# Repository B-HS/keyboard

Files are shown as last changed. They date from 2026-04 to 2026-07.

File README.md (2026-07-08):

# keyboard

| 브랜치 | 내용 | 뷰어 (GitHub Pages) |
| --- | --- | --- |
| [`v1`](https://github.com/B-HS/keyboard/tree/v1) | 49키 레이아웃 PCBA 뷰어 — React Three Fiber 기반 1세대 설계 | [b-hs.github.io/keyboard/v1](https://b-hs.github.io/keyboard/v1/) |
| [`v2`](https://github.com/B-HS/keyboard/tree/v2) | 49키 핸드와이어드 무선(BLE) + USB-C 키보드 빌드 — 2세대 | [b-hs.github.io/keyboard/v2](https://b-hs.github.io/keyboard/v2/) |
| [`split`](https://github.com/B-HS/keyboard/tree/split) | **현행** — split-65(65키 분리형) + split-keypad 모노레포. JSCAD 파라메트릭 케이스(FDM 7.5° 틸트, ESP32-C3 크래들), React 19 + three.js 뷰어, KiCad PCB(핫스왑·DO-35 손납땜·JLCPCB 발주본) | [b-hs.github.io/keyboard/split](https://b-hs.github.io/keyboard/split/) |

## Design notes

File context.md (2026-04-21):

# 49 Keyboard 프로젝트 Context

대화 재개용 요약. 이 파일 읽으면 전체 맥락 파악 가능.

**상태: JLC3DP 주문 완료 (SLA Resin + Threaded Insert)**

---

## 🎯 프로젝트 개요

**목표**: 49키 커스텀 키보드 자체 제작 (핸드와이어드, USB-C 유선, 3D 프린팅 케이스)

**핵심 스펙**:
- 레이아웃: 49키 (Row 0: 14×1u / Row 1: 1.5+11×1u+1.5u / Row 2: 2+10×1u+2u / Row 3: 1u+2×1.25u+2×2.75u(split spacebar)+5×1u)
- 컨트롤러: **LOLIN S3 Mini** (ESP32-S3FH4R2)
- 펌웨어: **RMK (Rust)** — Vial 네이티브
- 연결: **USB-C 유선 전용** (무선·배터리 완전 제거)
- 플레이트: **사용자 제공 STL** (`docs/models/plate/keyboard-plate.stl`)
- 케이스: **3D 프린팅 상/하 분할 + 샌드위치 구조**
- 타이핑 각도: **8° 틸트**
- 체결: **M3×6 button head × 8개** (모두 통일)

---

## 📂 프로젝트 구조

`/Users/gkn/keyboard/` (Git: github.com/B-HS/keyboard)

```
keyboard/
├── src/
│   ├── app.tsx                  # HMR accept + model re-build 트리거
│   ├── vite-env.d.ts
│   ├── components/
│   │   ├── viewer.tsx           # Blender/KiCad 스타일 카메라
│   │   └── controls.tsx         # 사이드바 + SLA toggle
│   └── models/
│       ├── layout.ts            # 49.json 파싱
│       ├── plate.ts             # buildPlate + loadPlateGeom (STL)
│       ├── case.ts              # 메인 케이스 빌더 (DEFAULT/SLA params)
│       ├── lolin.ts             # LOLIN S3 Mini 시각화
│       ├── switch.ts            # Cherry MX STL 로드
│       ├── keycap.ts            # Cherry MX 키캡 STL 로드
│       ├── stabilizer.ts        # 스태빌 STL 로드
│       ├── accessories.ts       # 고무발 / 스태빌 geometry
│       ├── reference.ts         # 49-final.jscad 파서
│       ├── defaults.ts          # 플레이트 파라미터 override
│       ├── build-params.ts
│       ├── build-solids.ts      # 조립 + SLA/default 선택
│       └── index.ts             # public API (loadPlateGeom 포함)
├── scripts/
│   ├── export.ts                # STL export + insert-spec 생성
│   ├── generate-spec.ts         # SVG/PNG spec 생성 (resvg-js)
│   ├── load-defaults.ts
│   └── verify.ts                # 치수 검증
├── docs/
│   ├── models/
│   │   ├── 49-final.jscad       # 레퍼런스 (fallback용)
│   │   ├── 49.json              # KLE 레이아웃 (truth source)
│   │   ├── plate/
│   │   │   ├── keyboard-plate.stl   # ⭐ 사용자 제공 plate (source of truth)
│   │   │   └── plate.jscad          # KLE-NG 출처
│   │   ├── switch/cherry mx.*
│   │   ├── keycap/STL/*.stl
│   │   └── stabilizer/*.stl
│   └── export/                  # JLC 주문용 산출물
│       ├── 1_case-top.stl               # PA12 self-tap
│       ├── 2_case-bottom.stl            # PA12 self-tap
│       ├── 1_case-top_SLA.stl           # SLA insert ⭐
│       ├── 2_case-bottom_SLA.stl        # SLA insert ⭐
│       ├── insert-spec-case-top.svg/png
│       └── insert-spec-case-bottom.svg/png
├── .github/workflows/deploy.yml
├── vite.config.ts               # base: '/keyboard/'
├── tsconfig.json                # noEmit: true
└── context.md
```

---

## 🏗 샌드위치 구조 (현재 설계)

```
위
│   [Keycaps]           ← 키캡 (외부)
│┌─────────────────────┐
││  Top Case           │ ← 상판 (뚜껑 역할, 옆벽 체결 4 insert)
││  ┌───────────────┐  │
││  │    Switches   │  │
││  ├───────────────┤  │
││  │     Plate     │  │ ← plate (사용자 STL, 기둥 위에 얹힘)
││  ┌─┴────────┐┌──┴┐  │
││  │          ││   │  │ ← 4 기둥 (하판에서 솟음, 상단 tilted)
││  │  LOLIN   ││   │  │
││  └──────────┘└───┘  │
│└──╧═══════════════╧──┘ ← 하판 (floor + pillars + 옆벽 체결 관통)
아래
```

**핵심 특징**:
- Plate은 하판의 4개 수직 기둥 위에 얹힘 (tilted pocket으로 8° 정렬)
- Top case는 뚜껑처럼 씌워져 옆벽 2/4·3/4 Y 위치에서 하판과 체결
- 조립 순서: 하판 → plate 장착 → 스위치/핸드와이어 → 상판 씌움

---

## 🔧 확정된 설계 결정 (최종)

1. **무선·배터리 완전 제거** → USB-C 유선 전용
2. **펌웨어 RMK** (Rust): Vial 네이티브, USB-C only
3. **MCU ESP32-S3** (LOLIN S3 Mini, 양면폼으로 하판 고정)
4. **케이스 샌드위치**: 하판(floor+기둥) + plate + 상판(뚜껑)
5. **Plate은 사용자 STL**: `keyboard-plate.stl`, 케이스가 자동으로 bounds에 맞춰 스케일
6. **8° 틸트**, pivot Y=plateBounds.minY, plateFrontBottomZ=10
7. **벽 두께 2mm**, case margin 2mm 사방
8. **Upper wall inset**: X=2, Y=2 (키캡-벽 gap: 좌우 1mm, 앞 2.48mm, 뒤 0.48mm)
9. **옆벽 체결**: Y=2/4, 3/4 위치, 좌우 총 4개 (6×6×6mm 보스)
10. **기둥**: 4개, plate 나사홀 위치, 수직 원기둥 (top만 tilted)
11. **Plate mount head clearance hole**: 상판 upper wall에 Ø5.2×3mm, tilted 정렬
12. **USB-C cutout 단순화**: 단일 관통홀 (Ø12.2×5.5 × depth 4mm, no taper)
13. **나사 통일**: M3×6 button head (head Ø5×H2, thread Ø3×L6) × 8개

---

## 📐 현재 케이스 파라미터 (case.ts)

### DEFAULT_CASE_PARAMS (PA12 SLS self-tap)

```ts
caseMarginFront/Back/Left/Right: 2
plateTiltDeg: 8
plateFrontBottomZ: 10

plateRecessWall: 7.5
wallThickness: 2
upperWallInsetX: 2
upperWallInsetY: 2
bottomThickness: 2.4

// Side fastener (옆벽 체결, 4개)
sideFastenerSize: 6          // 6×6mm 보스
sideFastenerHeight: 6.0      // 보스 높이
sideFastenerInsertRadius: 1.25   // Ø2.5 self-tap pilot
sideFastenerInsertDepth: 4.0
sideFastenerThroughRadius: 1.7   // Ø3.4 하판 관통
sideFastenerHeadRadius: 2.6      // Ø5.2 counterbore
sideFastenerHeadDepth: 2.0       // M3 button head 높이
sideFastenerYRatios: [0.5, 0.75]

// Plate mount pillar (하판 기둥, 4개)
plateMountPostRadius: 2.5        // Ø5 기둥
plateMountInsertRadius: 1.25     // Ø2.5 self-tap
plateMountInsertDepth: 4.0
plateMountHeadRadius: 2.6        // 상판 head clearance
plateMountHeadHeight: 2.5

// USB-C
usbCutoutWidth: 12.2, usbCutoutHeight: 5.5
usbCutoutCenterX: 9.7, usbCutoutCenterZ: 7.0
usbCutoutCornerRadius: 1.5

caseCornerRadius: 2
```

### SLA_CASE_PARAMS (SLA Resin + brass insert) — **주문한 버전**

```ts
...DEFAULT_CASE_PARAMS,
plateMountPostRadius: 3.0        // Ø6 (insert 주변 1.2mm wall)
plateMountInsertRadius: 1.8      // Ø3.6 (M3*4*5 insert용)
plateMountInsertDepth: 7.0       // 5mm insert + 2mm 여유
sideFastenerInsertRadius: 1.8    // Ø3.6
sideFastenerInsertDepth: 7.0
sideFastenerHeight: 8.0          // 7mm pocket + 1mm cap
```

### 최종 외곽 치수 (사용자 plate STL 기준)

- **Plate**: 271.65 × 82.10 × 1.5mm (사용자 STL)
- **Case outer**: 275.65 × 86.10mm
- **앞 높이**: ~18.5mm / **뒤 높이**: ~30.6mm

### 주요 위치 (case 좌표)

- **Plate 나사홀 (= 기둥 XY)**: (−8.999, 8.476), (256.649, 8.476), (−8.999, −67.625), (256.649, −67.625)
- **옆벽 체결**: X=−9/256.65, Y=−29.575 (2/4) / Y=−7.05 (3/4)
- **USB-C**: X=9.7, Z=7 (뒷벽)

---

## 🔨 케이스 빌드 순서 (case.ts)

### buildCaseTop (상판)
1. `outerShell` (사다리꼴 polygon extrude + R2 라운딩)
2. Z slicer로 Z ≥ bottomThickness 부분만
3. `steppedInnerCavity` subtract (plate top plane 기준 stepped)
4. `sideFastenerBosses` union (4개 옆벽 보스)
5. Subtract: `usbCutout`, `sideFastenerInsertHoles`, `plateMountHeadClearance`
6. `retessellate`

### buildCaseBottom (하판)
1. `floorSlab` (단순 roundedRectangle extrude, Z=0~2.4) — mesh 깔끔
2. `plateMountPillars` union (4개 수직 원기둥, 상단은 tilted plane으로 clip)
3. Subtract: `plateMountInsertPockets` (tilted), `sideFastenerThroughs` (counterbore + through hole)
4. `retessellate`

### Plate 렌더링
- `loadPlateGeom()` (src/models/plate.ts) — STL deserialize
- `plateBoundsFromGeom()` — bounds 자동 추출
- `applyPlateTransform()` — 8° tilt 적용

**상/하 분리**: 별도 함수 (slice 방식 버림). 완전히 독립된 빌드.

---

## 🧩 부품 (뷰어 토글)

| 부품 | 기본 | 비고 |
|---|---|---|
| Case Top | ON | |
| Case Bottom | ON | |
| Plate | ON | STL 로드 |
| Switches | ON | Cherry MX STL |
| LOLIN S3 Mini | ON | 양면폼 고정 가정 |
| Stabilizers | ON | STL |
| Keycaps | ON | 폭×R 매핑 |
| Foot Pads | ON | Ø6×2 × 4개, 코너 inset 5 |
| Phone | OFF | 크기 비교용 |
| WOBKEY Zen 65 | OFF | 크기 비교용 |
| **SLA Variant** | **OFF** | 체크하면 SLA_CASE_PARAMS 사용 |

**제거된 부품** (무선 관련): Battery Cover, Magnets, Batteries, Battery Contacts, Perf Board, Slide Switch

---

## 📦 Export (docs/export/)

```bash
bun run export
```

생성 파일:

| 파일 | 용도 |
|---|---|
| `1_case-top.stl` | PA12 SLS self-tap (대안) |
| `2_case-bottom.stl` | PA12 SLS self-tap (대안) |
| **`1_case-top_SLA.stl`** | **SLA Resin + M3*4*5 insert ⭐** |
| **`2_case-bottom_SLA.stl`** | **SLA Resin + M3*4*5 insert ⭐** |
| `insert-spec-case-top.svg/png` | JLC 참조 도면 (부품별) |
| `insert-spec-case-bottom.svg/png` | JLC 참조 도면 (부품별) |

Insert spec 자동 생성: `scripts/generate-spec.ts` + `@resvg/resvg-js`.

---

## 🛒 부품 / 주문 상태

### ✅ JLC3DP 주문 완료
- **1_case-top_SLA.stl** (SLA Resin + Threaded Insert M3*4*5 × 4)
- **2_case-bottom_SLA.stl** (SLA Resin + Threaded Insert M3*4*5 × 4)
- **Insert 총 8개** 자동 설치되어 배송
- JLC preview 노란 경고는 있지만 붉은 오류(unprintable) 없음

### ✅ 보유 부품
- LOLIN S3 Mini
- Cherry MX × 49, 키캡 STL
- MX Plate-mount 스태빌 (2u × 2 + 2.75u × 2)
- 1N4148 × 300, UEW 0.6mm × 10m, 만능보드 70×90
- M3×6 button head × 44 pack
- 고무발 Ø6×2
- HAKKO FX-600 + RS63 + 플럭스펜 + 캡톤 + 폼테이프
- 양면폼 테이프 (LOLIN 고정용)

### ❌ 추가로 필요할 수 있음
- **Plate 별도 주문** (keyboard-plate.stl — 사용자 파일 그대로)
- **Krytox 205g0** (스태빌 튜닝, 선택)

---

## 🔩 조립 순서

1. SLA 케이스 수령 (insert 8개 기 설치됨)
2. Insert에 M3 나사 시험 삽입 → 헛돌거나 안 박히면 JLC에 컴플레인
3. 하판 기둥 4개 위에 plate 얹기
4. **M3×6 × 4개** 위에서 plate 나사홀 → pillar insert 체결 (tilted 축)
5. Plate에 Cherry MX 스위치 clip 장착
6. 스위치에 다이오드 + UEW 에나멜선 핸드와이어
7. LOLIN S3 Mini에 와이어 납땜, 하판에 양면폼으로 고정
8. USB-C 연결 테스트
9. 상판을 위에서 씌움 (기둥 피하면서)
10. **M3×6 × 4개** 하판 아래에서 → 옆벽 insert 체결
11. 키캡 장착

---

## 🎨 개발 / 뷰어

```bash
bun run dev        # http://localhost:5173
bun run export     # STL + insert-spec 자동 생성
bun scripts/verify.ts   # 치수 검증 + plate STL alignment 확인
bun run build      # 프로덕션
```

**카메라 조작 (Blender/KiCad 스타일)**:
- LMB/MMB 드래그: 회전 (orbit)
- RMB or Shift+드래그: 이동 (pan)
- 휠: 커서 위치 기준 줌
- F 키: 모든 솔리드에 맞춰 프레이밍

**HMR**: `import.meta.hot.accept('./models/...')` — 모델 파일 변경시 자동 재렌더

---

## 🌐 GitHub Pages 배포

- `vite.config.ts`: `base: '/keyboard/'` (build 시만)
- `.github/workflows/deploy.yml`: main push → 자동 배포
- URL: **https://b-hs.github.io/keyboard/**

---

## 🔧 툴체인 버전

- **Vite 8.0.9**
- **React 19.2.5**
- **TypeScript 6.0.3**
- **Bun 1.3.0**
- `@resvg/resvg-js 2.6.2` (SVG→PNG 렌더링)

---

## ⏳ 남은 작업

- [ ] JLC3DP 배송 대기
- [ ] Plate 별도 주문 (`keyboard-plate.stl`)
- [ ] 배송 후 insert 품질 체크
- [ ] RMK `keyboard.toml` 작성 (Row/Col 핀 매핑, Vial 키맵)
- [ ] 핸드와이어 조립 + 테스트
- [ ] GitHub Pages 배포 확인

---

## 🐛 주요 수정 이력 (최신 순)

### 주문 직전 최종 수정
- **floorSlab** 단순화: `outerShell` slice → `roundedRectangle` extrude (JLC zigzag unprintable 에러 해결)
- **Pillar 수직화**: tilted cylinder → vertical cylinder + tilted top clip (mesh 깔끔)
- **SLA pocket**: Ø4×5 → **Ø3.6×7mm** (JLC 실제 hole 요구사항 반영)
- **SLA pillar** Ø5→Ø6 (Ø3.6 insert 주변 wall 1.2mm 확보)
- **플레이트 나사머리 clearance** 상판에 추가 (Ø5.2×3mm, tilt 정렬)
- **upperWallInsetY** 3 → 2 (back 음수 gap → 양수로)
- **plateFrontBottomZ** 9.75 → 10 (stab clip 여유)

### 구조 재설계
- **무선 관련 전면 제거**: 배터리 케이스·커버·자석·슬라이드 스위치·배터리·만능보드
- **샌드위치 구조 재설계**: plate를 하판 기둥에 직결, 상판은 뚜껑, 옆벽 2/4·3/4 체결 4개
- **플레이트 → STL 로드 방식**: 코드 generate 대신 사용자 파일 사용, 자동 bounds 추출
- **Case auto-scale to plate**: plate STL만 바꾸면 케이스 자동 맞춤

### 뷰어/카메라
- **Blender/KiCad 스타일 카메라**: LMB/MMB orbit, RMB pan, cursor zoom, F key framing
- **SLA toggle**: 뷰어에서 PA12 / SLA 전환

### 체결 규격 통일
- **M3×6 button head × 8개**로 완전 통일 (plate 4 + side 4)
- PA12 self-tap: Ø2.5 pilot × 4mm
- SLA insert: Ø3.6 × 7mm depth, M3*4*5 황동 insert

### Export 파이프라인
- **insert-spec SVG/PNG 자동 생성**: `scripts/generate-spec.ts` + resvg-js
- 부품별 2개 spec 파일 분리 (case-top / case-bottom)

### 초기 무선 제거 세션
- `case.ts`에서 battery tray, slide switch cutout, magnet boss/pocket, battery cover opening 코드 제거
- `accessories.ts`에서 `buildPerfBoard`, `buildSlideSwitch`, `buildBatteries`, `buildBatteryContacts`, `buildCaseMagnets`, `buildCoverMagnets`, `buildBatteryCover` 제거
- `build-solids.ts` · `controls.tsx` · `app.tsx`에서 관련 PartVisibility 전부 제거

---

## 🔗 외부 참조

- LOLIN S3 Mini: https://www.wemos.cc/en/latest/s3/s3_mini.html
- RMK: https://rmk.rs/ / https://github.com/HaoboGu/rmk
- Vial: https://vial.rocks/
- JLC3DP Threaded Insert: https://jlc3dp.com (SLA + Surface finish: Threaded Insert, type M3*4*5)

---

## 🎬 새 대화에서 시작

1. 이 파일 읽어 맥락 파악
2. `src/models/case.ts` 현재 상태 확인 (`DEFAULT_CASE_PARAMS` / `SLA_CASE_PARAMS`)
3. `bun run dev` (사용자 실행)
4. `bun run export` — STL + insert-spec 재생성
5. `bun scripts/verify.ts` — plate STL alignment 확인
6. JLC3DP 배송 완료시 insert 삽입 상태 검수

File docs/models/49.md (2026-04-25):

- 40% splite with `[`, `]`, `;`, `'`, `,`, `<`, `>`, `/` keys

```json
[["Esc","Q","W","E","R","T","Y","U","I","O","P","{\n[","}\n]","Back\nSpace"],
[{"w":1.5},"Tab","A","S","D","F","G","H","J","K","L",":\n;","\"\n'",{"w":1.5},"Enter"],
[{"w":2},"Shift","Z","X","C","V","B","N","M","<\n,",">\n.","?\n/\nUp",{"w":2},"Shift"],
["Control",{"w":1.25},"Option",{"w":1.25},"Command",{"w":2.75},"Space","Fn",{"w":2.75},"Space","Left","Down","Right\nDown","Fn\nRight"]]
```

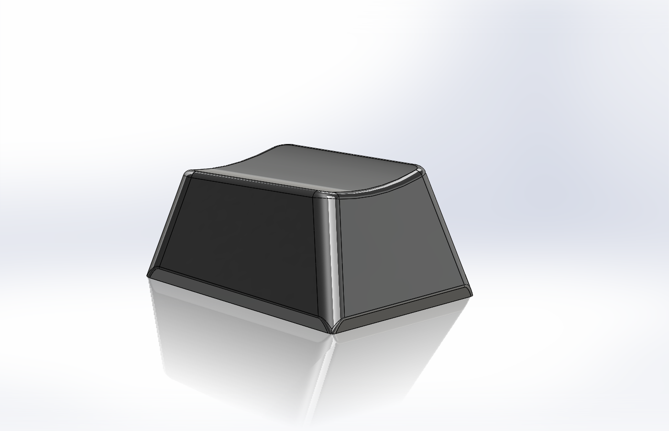
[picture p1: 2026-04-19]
docs/models/keycap/Cherry MX Keycap.PNG

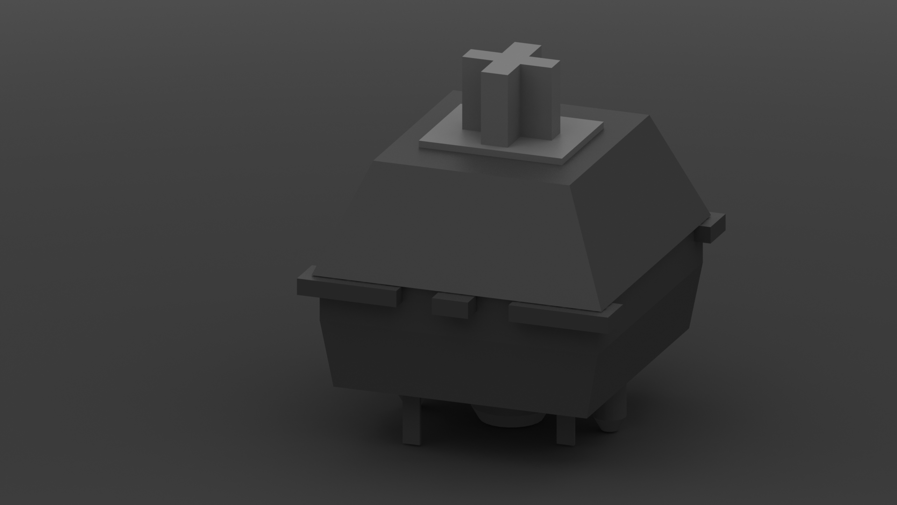
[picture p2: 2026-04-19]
docs/models/switch/cherry.JPG

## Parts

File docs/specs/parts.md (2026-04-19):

# 49 Keyboard 부품 리스트

49키 핸드와이어드 + 무선(BLE) + USB-C 키보드 빌드.

## 확정 사양

| 항목 | 값 |
|---|---|
| 레이아웃 | 49키 (`docs/keyboard-plate.jscad` 기반) |
| 컨트롤러 | LOLIN S3 Mini (ESP32-S3FH4R2) |
| 펌웨어 | RMK (Rust, Vial 네이티브) |
| 키맵 편집기 | Vial (vial.rocks) |
| 연결 | USB-C 유선 + BLE 5.0 무선 자동 전환 |
| 전원 | 3×AA 알카라인 교체형 |
| 배터리 구획 | 케이스 일체형 슬롯 + 스프링 접점 |
| 커버 | 슬라이드 + 스냅핏 |
| 매트릭스 | 7×7 + diode per key |
| 플레이트 | 파라메트릭 (STL 출력 예정) |
| 케이스 | JSCAD 커스텀 3D 프린팅 |

---

## 부품 마스터 테이블

| 상태 | 카테고리 | 부품 | 수량 | 비고 |
|:----:|---|---|:----:|---|
| `[x]` | 컨트롤러 | LOLIN S3 Mini (ESP32-S3FH4R2) | 1 | Xtensa LX7, 27 GPIO, USB-C, BLE 5.0 |
| `[x]` | 전원 | AA 스프링 접점 세트 10개 | 1 | 콤비×2 + 플레이트×1 + 스프링×1 필요 |
| `[x]` | 전원 | TPS63020 Buck-Boost 3.3V 모듈 | 1 | 3.3V 출력 버전. PS→GND 필수 |
| `[x]` | 전원 | GVMRZ 슬라이드 스위치 (SMD) | 1 | 케이스 내부 배치, 1.5mm 핀 간격 |
| `[x]` | 전원 | AA 알카라인 배터리 | 3+예비 | 장기 미사용 시 분리 |
| `[x]` | 매트릭스 | 1N4148 다이오드 (DO-35) | 300 | 극성: 검은 띠=Cathode(−) |
| `[x]` | 매트릭스 | 에나멜선 0.6mm 10m (UEW) | 1 | 22 AWG 상당, 인두 330~350°C |
| `[x]` | 매트릭스 | 만능보드 7×9cm (70×90mm) 양면 FR4 | 1 | LOLIN + TPS63020 + 슬라이드 스위치 마운트용 |
| `[x]` | 스위치 | Cherry MX 호환 스위치 | 49 | 보유 |
| `[x]` | 스위치 | 키캡 세트 | 49 | 보유 |
| `[x]` | 스위치 | MX Plate-mount 스태빌라이저 2u | 2세트 | 보유 (좌/우 Shift) |
| `[x]` | 스위치 | MX Plate-mount 스태빌라이저 6.25u | 1세트 | 보유 (Space) |
| `[x]` | 연결 | USB-C 데이터 케이블 | 1 | 데이터 지원 확인 |
| `[x]` | 조립 | M3 하드웨어 키트 (나사+너트+스페이서 176pcs) | 1 | M3×6mm 44개 + 너트 44개 + F-F/F-M 스페이서 다양 |
| `[x]` | 조립 | M3 열 인서트 키트 (M2~M6, 220pcs) | 1 | M3×4×4 25개 + M3×5×4 25개 + 기타 다양 |
| `[x]` | 조립 | 고무발 실리콘 6×2mm 자가접착 | 100 | 케이스 바닥 (필요 시 겹쳐 사용) |
| `[x]` | 소모품 | 희성 일반 유연납 0.6mm 500g | 1 | Sn63/Pb37 |
| `[x]` | 소모품 | 엑소 QSP-57 솔더링 페이스트 | 1 | 친환경 페이스트 |
| `[x]` | 소모품 | 켐트로닉스 CW-8200 플럭스펜 | 1 | No-clean 플럭스 펜 |
| `[x]` | 소모품 | 3M 8997 캡톤 PI테이프 15mm × 33m | 1 | 절연·교차점·열 보호 (열수축튜브 대체) |
| `[x]` | 소모품 | 3M 4421 양면 폼테이프 10mm × 10m | 1 | 모듈·스위치·배터리 고정 |
| `[x]` | 도구 | 글루건 + 글루 스틱 | 1 | 보유. AA 스프링 접점 고정용 |
| `[x]` | 도구 | HAKKO FX-600 인두기 | 1 | T18 팁 시리즈, 200~500°C |
| `[x]` | 도구 | HAKKO FH300 스탠드 | 1 | FX-600 전용 |
| `[x]` | 도구 | HAKKO T18-D24 팁 (치즐 2.4mm) | 1 | 일반 작업용 |
| `[x]` | 도구 | HAKKO T18-D08 팁 (치즐 0.8mm) | 1 | SMD 세밀 작업용 |
| `[x]` | 도구 | HAKKO WICK FR551-3015 (솔더윅) | 1 | 납 제거 |
| `[x]` | 도구 | HAKKO 599-029 클리닝 와이어 | 1 | 팁 청소 |
| `[x]` | 도구 | PLATO 170S 정밀 니퍼 (플러시 컷) | 1 | 구리 0.8mm 까지 절단 |
| `[x]` | 도구 | 새한 ST-850A 디지털 멀티미터 | 1 | 매트릭스 QA |
| `[ ]` | 출력 | 스위치 플레이트 3D 프린팅 | 1 | `docs/keyboard-plate.jscad` |
| `[ ]` | 출력 | 케이스 상부 3D 프린팅 | 1 | JSCAD 설계 후 |
| `[ ]` | 출력 | 케이스 하부 3D 프린팅 | 1 | JSCAD 설계 후 |

---

## 기타 (49키 빌드와 무관)

| 상태 | 부품 | 용도 |
|:----:|---|---|
| `[x]` | ESP32 2.8" 스마트 디스플레이 (CYD, LVGL) | 별도 실험용 |

---

## 빌드 단계 체크리스트

### Phase 1. CAD 설계
- [x] 49.json 레이아웃 확정
- [x] 플레이트 파라메트릭 모델 (`docs/keyboard-plate.jscad`)
- [x] JSCAD 뷰어 셋업 (`viewer/`)
- [ ] 케이스 상부 프레임 설계
- [ ] 케이스 하부 설계 (배터리 슬롯 + 컨트롤러 마운트 + 슬라이드 커버)
- [ ] 최종 STL 내보내기

### Phase 2. 부품 주문
- [x] 전원 부품 (접점, TPS63020, 스위치)
- [x] 매트릭스 부품 (다이오드, 선, 만능보드)
- [x] 조립 하드웨어 (나사, 너트, 스페이서, 고무발, 열 인서트)
- [x] 소모품 (납, 플럭스, 테이프)
- [x] 도구 (인두기 + 팁 + 니퍼 + 멀티미터)
- [ ] 3D 프린팅 의뢰

### Phase 3. 하드웨어 조립
- [ ] 스위치를 플레이트에 장착
- [ ] 스태빌라이저 설치 (2u×2, 6.25u×1)
- [ ] 만능보드에 부품 고정 (LOLIN, TPS63020, 슬라이드 스위치)
- [ ] 다이오드 납땜 (49개)
- [ ] Row 배선 (UEW, 7줄)
- [ ] Col 배선 (UEW, 7줄)
- [ ] 배터리 접점 설치
- [ ] 전원 회로 (접점 → 스위치 → TPS63020 → LOLIN 3.3V)
- [ ] LOLIN GPIO ↔ 매트릭스 14줄 배선
- [ ] 멀티미터 QA
- [ ] 케이스 조립

### Phase 4. 펌웨어
- [ ] Rust + ESP-IDF toolchain 설치
- [ ] RMK 리포지토리 클론
- [ ] `keyboard.toml` 작성 (49키 매트릭스 + GPIO 매핑)
- [ ] 첫 빌드 + USB-C 플래싱
- [ ] vial.rocks 키맵 편집 테스트
- [ ] BLE 페어링 테스트 (Mac/Win/iOS)
- [ ] 슬립/절전 튜닝

### Phase 5. 마감
- [ ] 고무발 부착
- [ ] 배터리 삽입 + 무선 동작 확인
- [ ] 장기 사용 테스트

---

## 의사결정 로그

| 결정 | 사유 |
|---|---|
| 펌웨어 RMK | QMK+BT+VIA 조합 불가. RMK = Vial(VIA 호환) 네이티브 + BLE/USB 듀얼 |
| MCU ESP32-S3 | nRF52840 대비 국내 구매 용이, USB-C 네이티브, RMK 공식 지원 |
| LOLIN S3 Mini | 27 GPIO, 공식 제품, USB-C |
| 3×AA 알카라인 교체형 | 리튬 수명(~2년) 대비 반영구. 장기 미사용 시 분리 가능 |
| 통합 슬롯 + 스프링 접점 | 완제품 홀더 대비 슬림. AA 표준 치수로 사전 설계 가능 |
| 슬라이드 + 스냅핏 커버 | 공구 없이 교체, 외부 돌출 없음 |
| UEW 0.6mm 단일 | 국내 구매 가능한 굵기. Row/Col 통일 단순화 |
| TPS63020 Buck-Boost | AA 전압 변동(4.5→2.7V) 전체에서 3.3V 유지 |
| 슬라이드 스위치 내부 배치 | 외부 돌출 없음. 배터리 커버 열어 조작 |
| 유연납 0.6mm | 작업성 우위. 환기 + 손 세정으로 안전 관리 |
| 캡톤 + 폼테이프 | 열수축튜브·순간접착제 대체. 가열 도구 불필요 |
| 만능보드 7×9cm | 부품 마운트 전용 (매트릭스는 직접 배선) |

---

## 참조

- **LOLIN S3 Mini 공식**: https://www.wemos.cc/en/latest/s3/s3_mini.html
- **RMK 문서**: https://rmk.rs/
- **RMK GitHub**: https://github.com/HaoboGu/rmk
- **Vial**: https://get.vial.today/ · 웹: https://vial.rocks/
- **ESP32-S3 Datasheet**: https://www.espressif.com/sites/default/files/documentation/esp32-s3_datasheet_en.pdf
- **자세한 부품 치수**: `parts_specification.md`

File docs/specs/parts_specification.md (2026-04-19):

# 부품 치수·사양 명세

케이스·플레이트 JSCAD 설계에 사용되는 각 부품의 실제 치수.

구분:
- **✅ 확정**: 공식 데이터시트/사용자 제공/표준치 기반
- **⏳ 실측 필요**: 실물 도착 후 사용자가 재봐야 함
- **❓ TBD**: 아직 결정/확인 안 됨

---

## 1. 플레이트 / 레이아웃

### 1.1 플레이트 아웃라인 ✅
소스: `docs/keyboard-plate.jscad` (KLE-NG 생성, `viewer/src/models/reference.ts` 파서로 자동 반영)

| 항목 | 값 |
|---|---|
| 크기 | 271.65 × 83.15 mm |
| 두께 | 1.5 mm |
| 코너 R | 1.0 mm |
| 중심 좌표 | (123.825, -29.575) |

### 1.2 키 배치 ✅
소스: `49/49.json` KLE 레이아웃

| 항목 | 값 |
|---|---|
| 총 키 수 | 49 |
| 키 피치 | 19.05 mm (1u) |
| 행 수 | 4 |
| 키 bounding box | X [-9.525, 257.175], Y [-66.675, 9.525] |

### 1.3 스위치 컷아웃 ✅

| 항목 | 값 |
|---|---|
| 크기 | 14 × 14 mm |
| 코너 R | 0.5 mm |

### 1.4 스태빌라이저 컷아웃 ✅
대상: `2,0` (2u), `2,12` (2u), `3,6` (6.25u)

| 항목 | 값 |
|---|---|
| 패드 크기 | 7 × 15 mm |
| 패드 코너 R | 0.5 mm |
| Y 오프셋 (키 중심 기준) | -1.5 mm |
| 2u 스페이싱 | ±11.938 mm |
| 6.25u 스페이싱 | ±50 mm |

### 1.5 나사홀 ✅

| 항목 | 값 |
|---|---|
| 개수 | 4 (코너) |
| 반경 | 1.5 mm (M3 통과) |
| 아웃라인 엣지로부터 마진 | 3.0 mm |
| 위치 | (-9, -68.15), (256.65, -68.15), (-9, 9), (256.65, 9) |

---

## 2. 컨트롤러

### 2.1 LOLIN S3 Mini (ESP32-S3FH4R2)
소스: `dim_s3_mini_v1.0.0.pdf` 공식 치수

| 항목 | 값 |
|---|---|
| 바운딩 박스 | **25.4 × 34.3 mm** |
| PCB 두께 | 1.6 mm |
| 전체 두께 (부품 포함) | ~4~5 mm |
| USB-C 위치 | 짧은 변 (25.4 mm) 상단 끝 (34.3mm 중 한쪽 끝) |
| USB-C 엣지 범위 | 엣지 좌측 2.5 mm ~ 우측 2.5 mm (폭 20.4 mm) |
| USB-C 엣지 돌출량 | ~1 mm (추정, 실측 권장) |
| ANT (BLE 안테나) | 우측 상단 코너, Ø2 mm, 상단에서 7.7 mm |
| 핀헤더 | 2×16 (양측) 2.54 mm 피치 |
| 좌측 핀헤더 | 좌측 엣지에서 1.27 mm 안쪽 |
| 우측 핀헤더 | 우측 엣지에서 1.27 mm 안쪽 |
| 최하단 핀 위치 | 상단에서 8.2 mm 이후부터 시작 (8.8 mm down) |
| 마운트 홀 | **없음** |
| 동작 전압 | 3.3V |

**핀 사용 제약**:
- 스트랩 핀 (부팅 영향): IO0, IO3, IO45, IO46 — 가급적 회피
- USB: IO19 (D−), IO20 (D+) — USB 쓸 땐 건드리지 말 것
- RGB LED (WS2812): IO47 — 안 쓰면 GPIO 로 자유
- EN 버튼, BOOT (IO0) 버튼 — 온보드 존재

**JSCAD 케이스 설계 반영**:
- LOLIN 마운트 영역: **25.4 × 34.3 mm + 2~3mm 여유**
- 마운트 홀 없으므로 **만능보드에 핀헤더로 고정** (만능보드가 고정 역할)
- USB-C 는 25.4mm 짧은 변 한쪽 끝, **케이스 측면 컷아웃 필요**
- USB-C 컷아웃: **폭 9mm × 높이 4mm** 정도 (USB-C 표준)

---

## 3. 전원 회로

### 3.1 AA 배터리 ✅
IEC 표준

| 항목 | 값 |
|---|---|
| 지름 | Ø14.5 mm (max 14.5, nominal 14.0) |
| 길이 | 50.5 mm (max 50.5, nominal 50.0) |
| 양극 돌기 | +1.5 mm |
| 음극 평면 | — |

### 3.2 AA 스프링 접점 세트 ✅
사용자 제공 이미지 기준 바운딩 박스:

**콤비 타입** (셀 간 직렬 연결, 2개 필요):
| 타입 | 길이 | 폭 |
|---|---|----|
| 콤비 A | 21 mm | 9 mm |
| 콤비 B | 24 mm | 9 mm |
| 콤비 C | 20 mm | 9 mm |

**단품 타입** (양 끝 종단):
| 타입 | 크기 |
|---|---|
| 스프링 + 플레이트 분리쌍 | 8~9.5 × 9 mm |

**고정 방식**: **글루건 접착** — 정밀 포켓 설계 불필요

케이스는 접점 형상 상관없이 **평면 벽**만 제공. 조립 시 벽에 접점 대고 글루건으로 고정.

**설계 반영**:
- AA 슬롯: 원통 Ø15.2 × 54 mm
- 슬롯 양 끝에 **접점 벽** (높이 12 mm, 두께 2 mm)
- 벽 뒤쪽 배선 통로: Ø2 mm 관통 홀 1개
- 추가 잠금·포켓 없음 (모두 글루건으로 해결)

### 3.3 TPS63020 Buck-Boost 모듈 ✅
**만능보드에 납땜해서 통합** — 케이스 설계에 개별 치수 반영 불필요 (만능보드 바운딩만 중요)

| 항목 | 값 |
|---|---|
| 입력 전압 범위 | 1.8~5.5V |
| 출력 전압 | 3.3V (주문 시 선택) |
| 대기 전류 (PS 모드) | 50 μA |
| 최대 출력 전류 | 3A |
| 마운트 | 만능보드 70×90mm 영역 내 |
| 핀 | VIN / VOUT / GND / EN / PS / PG |

### 3.4 GVMRZ 슬라이드 스위치 (SMD) ✅
사용자 제공 이미지 기준

| 항목 | 값 |
|---|---|
| 바운딩 박스 | 6.8 × 2.8 mm |
| 본체 높이 | 2.7 mm |
| 핸들 높이 (H) | 1.5 / 2.0 / 2.5 mm (버전별) ⏳ 구매 버전 확인 필요 |
| 스트로크 (Travel) | 1.5±0.15 mm |
| 단자 간격 | 1.5 mm |
| 단자 수 | SPDT 3핀 (SMD) |
| 마운트 홀 (옵션) | 2 × Ø0.8 mm, 간격 3 mm |
| 조작력 | 160±20 gf |
| 전기 | 12V DC / 100 mA |
| 재질 | PA46 하우징 + 은 도금 황동 단자 |

**실측 필요 ⏳**: 구매한 핸들 높이 버전 (H=1.5 / 2.0 / 2.5)

---

## 4. 매트릭스 부품

### 4.1 1N4148 다이오드 ✅

| 항목 | 값 |
|---|---|
| 패키지 | DO-35 (유리) |
| 본체 크기 | ~3.0 × 1.5 mm (L×Ø) |
| 리드 지름 | 0.55 mm |
| 리드 길이 | ~25 mm (원래), 작업 시 5~10mm 로 절단 |
| 극성 | 검은 띠 = Cathode (−) |

### 4.2 UEW 에나멜선 ✅

| 항목 | 값 |
|---|---|
| 지름 | 0.6 mm (구리 심선) |
| 피복 두께 | ~0.02 mm (폴리우레탄) |
| 외경 | ~0.64 mm |
| AWG 등가 | 22 AWG |
| 길이 | 10 m |

### 4.3 만능보드 ✅

| 항목 | 값 |
|---|---|
| 크기 | 70 × 90 mm (7×9cm) |
| 두께 | 1.6 mm (FR4 표준) |
| 홀 피치 | 2.54 mm |
| 홀 지름 | 1.0 mm |
| 양면 | 예 |

### 4.4 Cherry MX 스위치 ✅

| 항목 | 값 |
|---|---|
| 본체 크기 (top) | 15.6 × 15.6 mm |
| 플레이트 컷아웃 | 14.0 × 14.0 mm (표준) |
| 플레이트 두께 수용 | 1.5 mm (표준 스위치 기준) |
| 총 높이 (플레이트 위) | ~11 mm |
| 총 높이 (플레이트 아래) | ~5 mm |
| 핀 수 | 2 (전기) + 3 (플라스틱 정렬 핀) |
| 핀 위치 (전기) | 센터에서 (-3.81, 2.54) 와 (2.54, 5.08) |

---

## 5. 조립 하드웨어

### 5.1 M3 나사 ✅ (키트에 다양한 길이)

| 항목 | 값 |
|---|---|
| 지름 (수나사) | 3.0 mm |
| 관통홀 권장 | 3.4~3.5 mm |
| 체결부 (캡/판헤드) | Ø5.5 mm, 2.5mm 두께 |

### 5.2 M3 너트 ✅

| 항목 | 값 |
|---|---|
| 대각선 (point-to-point) | 6.35 mm |
| 대변 (flat-to-flat) | 5.5 mm |
| 두께 | 2.4 mm |
| 육각 포켓 설계 | 6.0 mm 대각선, 2.5 mm 깊이 |

### 5.3 M3 열 인서트 ✅ (키트 기준)

| 항목 | 값 |
|---|---|
| 나사산 | M3 |
| 외경 | Ø4.0 mm |
| 길이 | 3 / 4 / 5 mm (주로 **4 mm** 사용 예정) |
| 설치 홀 | Ø3.8 mm (OD 0.2 작게) |
| 설치 온도 | 200~250°C |

### 5.4 고무발 ✅

| 항목 | 값 |
|---|---|
| 지름 | Ø6 mm |
| 높이 | 2 mm |
| 재질 | 실리콘 |
| 부착 | 자가접착 |

### 5.5 캡톤 테이프 ✅

| 항목 | 값 |
|---|---|
| 폭 | 15 mm |
| 길이 | 33 m |
| 두께 | ~0.06 mm (필름 0.025 + 접착 0.035) |
| 내열 | 260°C |

### 5.6 3M 4421 양면 폼테이프 ✅

| 항목 | 값 |
|---|---|
| 폭 | 10 mm |
| 길이 | 10 m |
| 두께 | 0.8 mm (PE 폼) |
| 색상 | 흰색 |

---

## 6. 케이스 설계 파라미터

### 6.1 케이스 바운딩 (확정) ✅

| 항목 | 값 |
|---|---|
| 외부 바운딩 (W × D) | 271.65 × 83.15 mm (플레이트와 동일) |
| **외부 높이** | **18 mm** (표준) |
| 내부 바닥~플레이트 간격 | 10 mm (스페이서 높이) |
| 벽 두께 | 2.5~3 mm (3D 프린팅 기준) |
| 코너 R (외부) | 1.0 mm (플레이트 R과 일치) |

### 6.1.1 케이스 재질 (후보) ✅

| 옵션 | 재질 | 매끈함 | 무게 | 가공 |
|---|---|---|---|---|
| 🥇 1순위 | **SLA Resin** | 최상 | 중 | 외주 SLA 3D 프린팅 |
| 🥈 | ABS + 아세톤 훈증 | 광택 | 가벼움 | FDM + 후처리 |
| 🥉 | PETG | 매끈 | 가벼움 | FDM 3D 프린팅 |
| 후보 | PLA+ / ASA | 매끈 | 가벼움 | FDM |

### 6.1.2 플레이트 재질 (확정) ⭐

**PC (Polycarbonate) 1.5mm** — Thocky + 경량 최적

| 항목 | 값 |
|---|---|
| 재질 | Polycarbonate 시트 |
| 두께 | 1.5 mm (표준) |
| 사운드 | Deep thocky, 마쉬멜로우 |
| 밀도 | 1.20 g/cm³ |
| 제작 | 레이저 컷 또는 CNC |
| 소스 | `docs/keyboard-plate.dxf` (DXF 파일) |
| 주문 | 국내 레이저컷 업체 또는 SendCutSend (해외) |

### 6.2 내부 공간 분배 (잠정) ⏳

| 영역 | 용도 | 예상 치수 |
|---|---|---|
| 배터리 구획 | 3×AA 슬롯 | 55 × 55 × 15 mm 내외 |
| 컨트롤러 마운트 | LOLIN + TPS63020 + 스위치 | 50 × 40 × 8 mm |
| 만능보드 영역 | 부품 마운트 | 70 × 90 mm |
| 다이오드/배선 공간 | 플레이트 아래 | 플레이트 전역 |

### 6.3 슬라이드 커버 (잠정) ⏳

| 항목 | 값 |
|---|---|
| 슬라이드 레일 | TBD ❓ |
| 스냅핏 훅 | TBD ❓ |
| 커버 두께 | 2 mm |
| 접근: 배터리 교체 + 슬라이드 스위치 조작 | 확정 |

---

## 7. 사용자로부터 필요한 추가 정보

### ✅ 결정 완료

1. GVMRZ 슬라이드 스위치 핸들: **H=1.5 mm**
2. 케이스 외부 전체 높이: **18 mm (표준)**
3. 배터리 커버 잠금: **슬라이드 + 스냅핏**
4. 플레이트 재질: **PC 1.5 mm (레이저 컷)**
5. LOLIN 치수 확보: `dim_s3_mini_v1.0.0.pdf`
6. TPS63020: 만능보드 납땜 (개별 치수 불필요)

### 🟡 실물 도착 후 실측 (설계 후 조정 가능)

7. ~~AA 스프링 접점 실측~~ → **글루건 고정으로 해결**. 정밀 치수 불필요

### 🟢 선택 (나중 결정 가능)

8. **케이스 3D 프린팅 재질** — 후보:
    - 🥇 SLA Resin (외주) — 매끈함 최상
    - 🥈 ABS + 아세톤 훈증 — 광택
    - 🥉 PETG — 무난
    - PLA+ / ASA — 대안

9. **플레이트 주문처**
    - 국내 아크릴 레이저컷 업체 (DXF 파일 보내 주문)
    - 해외 SendCutSend (DXF 업로드 자동 견적)

---

## 변경 이력

- 2026-04-20: 초안 작성

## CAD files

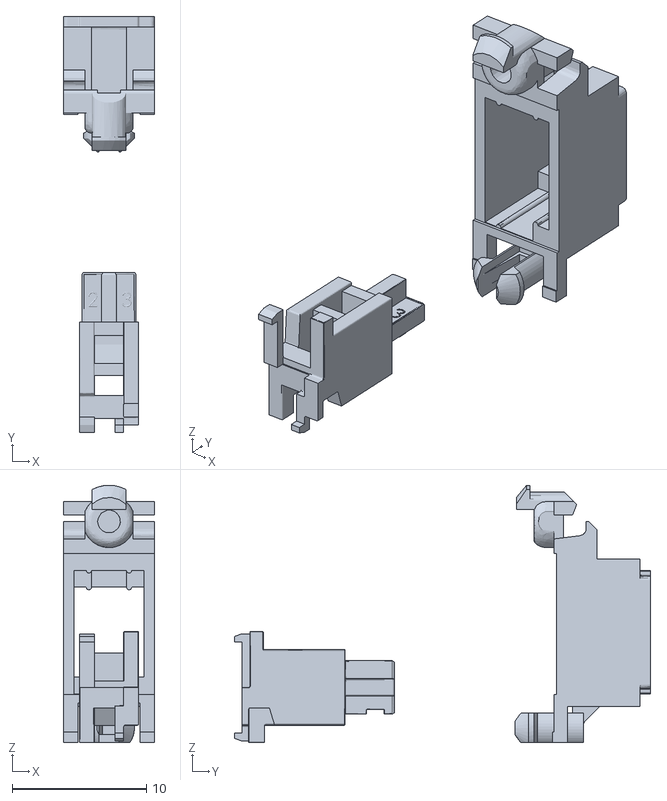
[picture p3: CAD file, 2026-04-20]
dist/assets/Cherry MX Stabilizers-BdvURbJf.stl
6.80 x 31.0 x 19.2

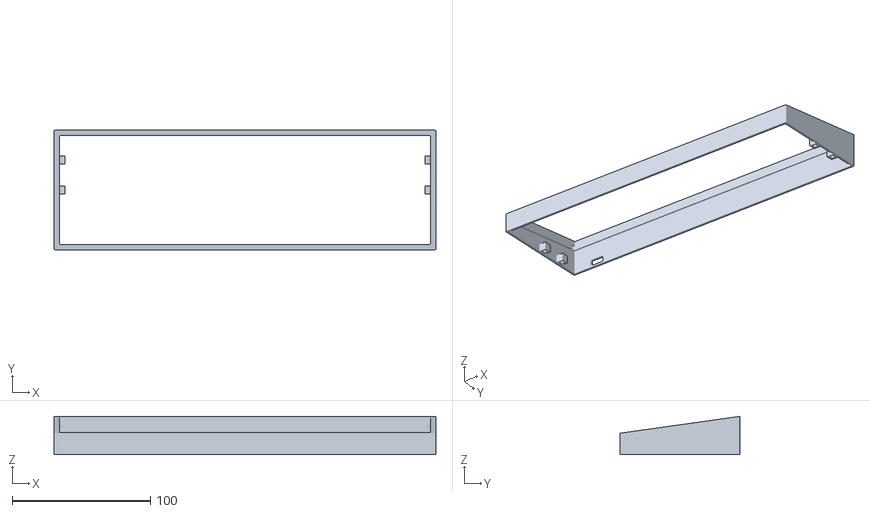
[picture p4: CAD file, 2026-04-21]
docs/export/1_case-top.stl
276.1 x 86.6 x 27.7

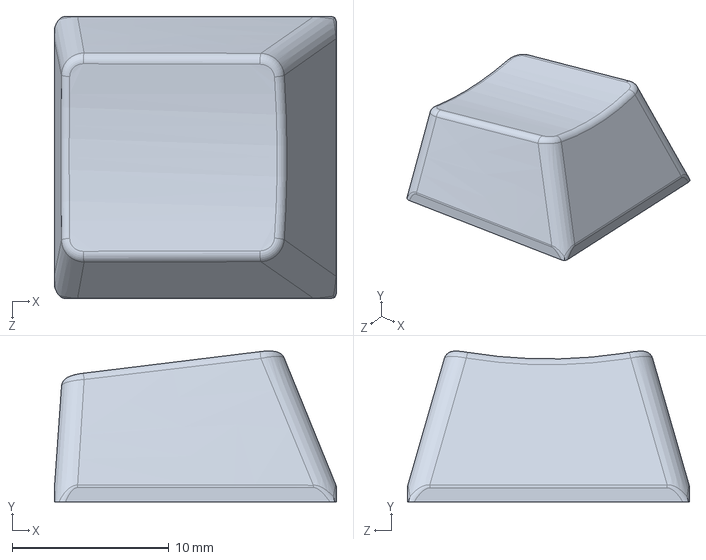
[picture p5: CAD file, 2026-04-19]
docs/models/keycap/Cherry MX Keycap.SLDPRT
18.0 x 9.64 x 18.0 mm

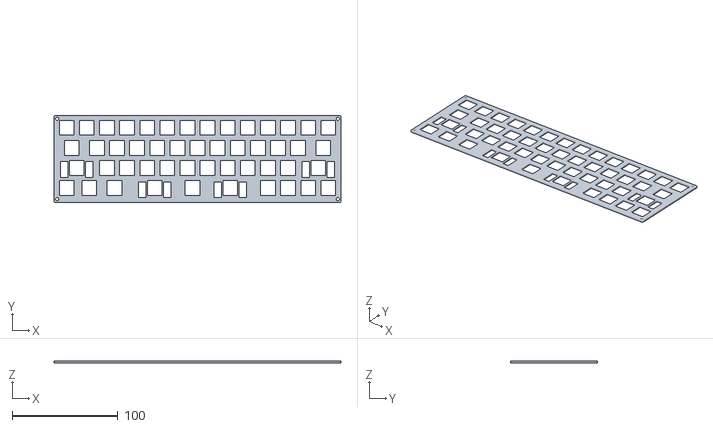
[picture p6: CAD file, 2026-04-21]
docs/models/plate/keyboard-plate.stl
271.6 x 82.1 x 1.50

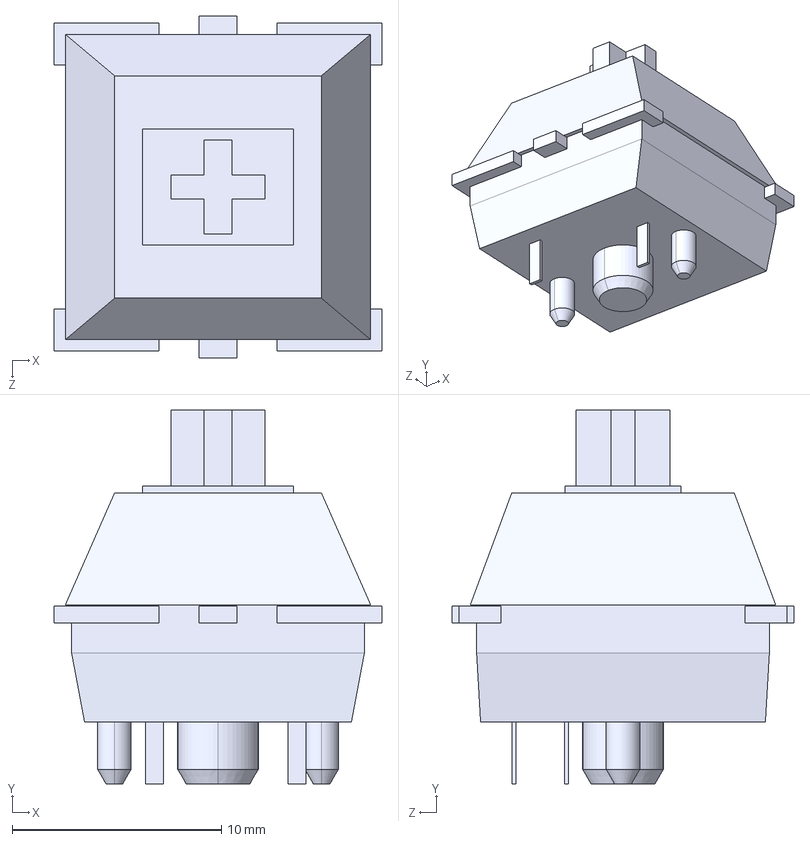
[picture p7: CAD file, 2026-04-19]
docs/models/switch/cherry mx.STEP
15.6 x 17.9 x 16.3 mm

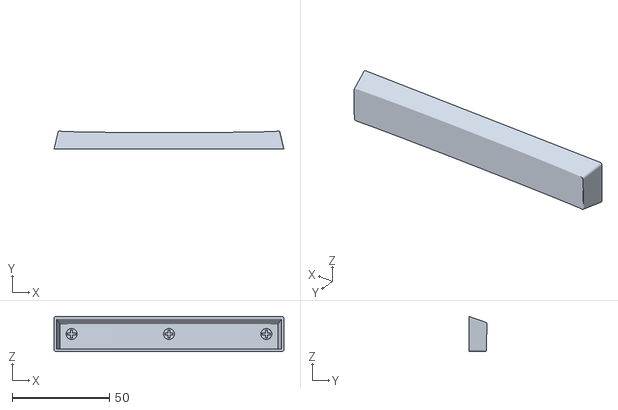
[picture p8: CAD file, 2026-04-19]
dist/assets/1x6.25 R3-jSgTeDu0.stl
118.1 x 9.20 x 18.0

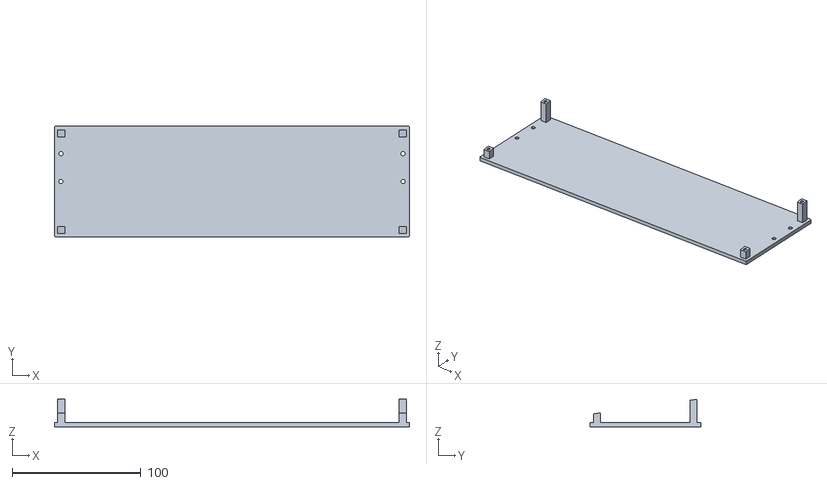
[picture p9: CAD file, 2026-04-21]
docs/export/2_case-bottom.stl
276.1 x 86.6 x 21.4

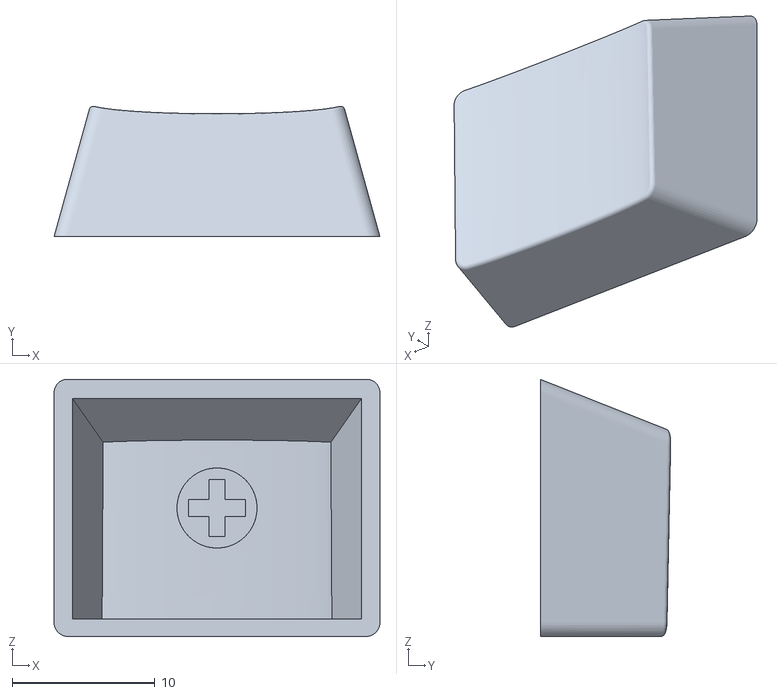
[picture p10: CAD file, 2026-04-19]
dist/assets/1x1.25 R3-Bbup1Px_.stl
22.8 x 9.12 x 18.0

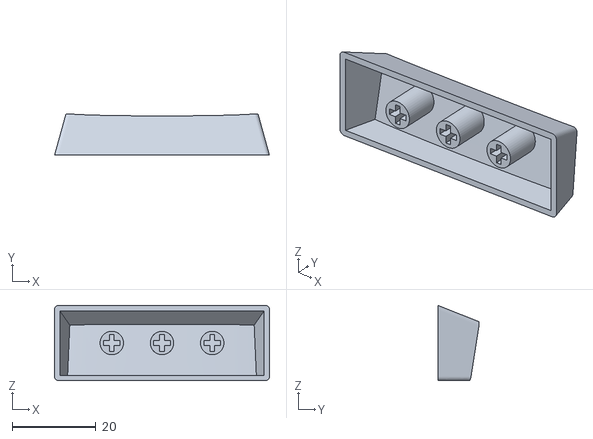
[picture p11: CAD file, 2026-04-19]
dist/assets/1x2.75 R1-B4GsleKx.stl
51.4 x 9.91 x 18.0

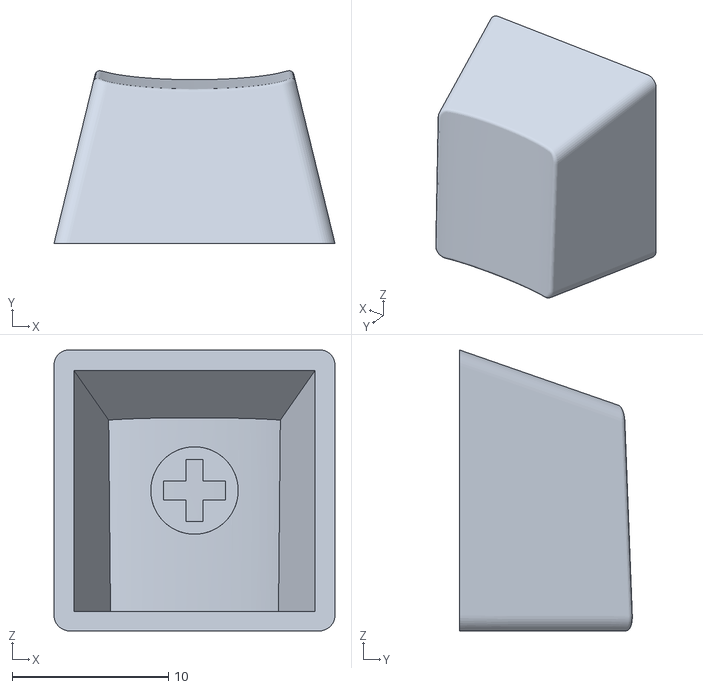
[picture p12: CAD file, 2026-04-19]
dist/assets/1x1 R4-DOHI7gOD.stl
18.0 x 11.1 x 18.0

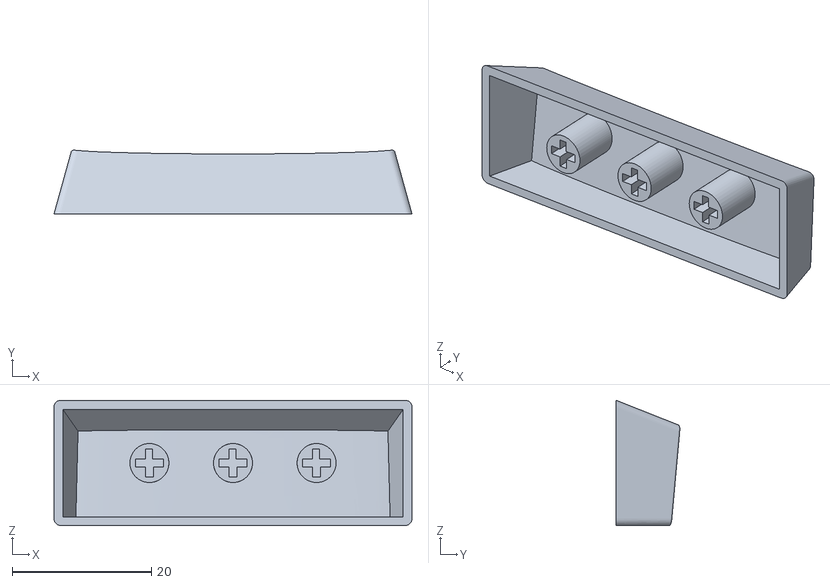
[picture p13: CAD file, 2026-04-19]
dist/assets/1x2.75 R2-CEoDoVIs.stl
51.4 x 9.14 x 18.0

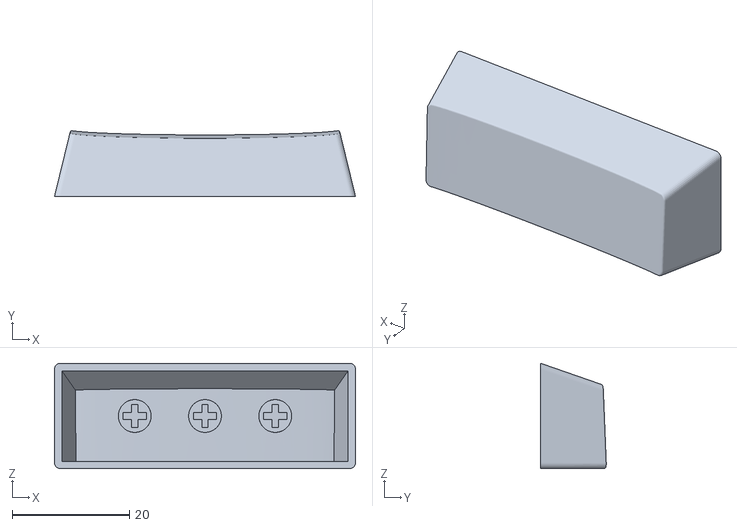
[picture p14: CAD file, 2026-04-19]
dist/assets/1x2.75 R4-TEObgMYb.stl
51.4 x 11.2 x 18.0

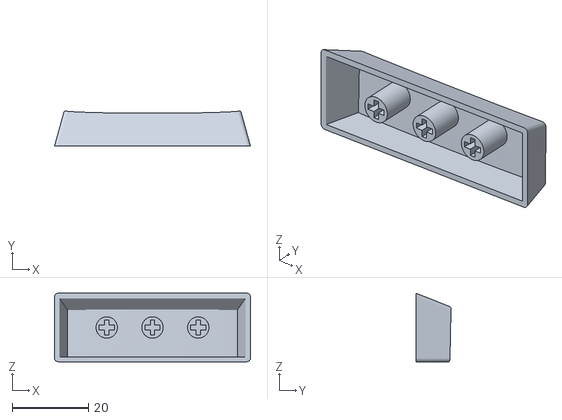
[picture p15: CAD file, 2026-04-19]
dist/assets/1x2.75 R3-CVz7YH08.stl
51.4 x 9.18 x 18.0

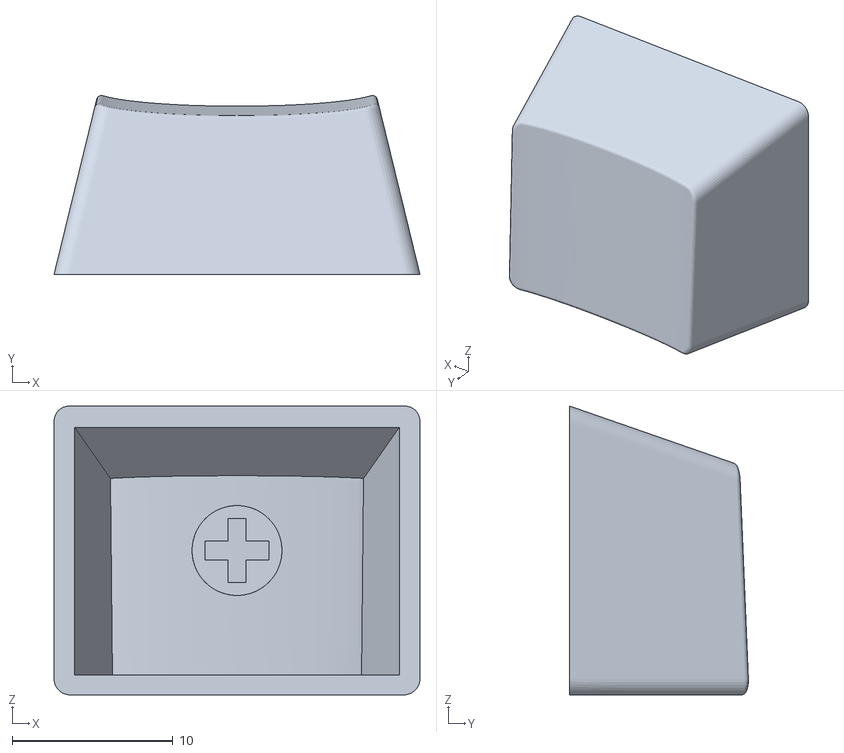
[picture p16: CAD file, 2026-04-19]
dist/assets/1x1.25 R4-DaAgSSmp.stl
22.8 x 11.1 x 18.0

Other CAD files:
dist/assets/1x1.5 R1-AGZeUWU5.stl
dist/assets/1x2 R3-Cc2chU7F.stl
dist/assets/1x2 R2-B7yHtqF7.stl
dist/assets/1x1.75 R2-CVJApBdu.stl
dist/assets/1x1 R1-C5EL7BkD.stl
dist/assets/1x1 R2-BPDmK7m8.stl
dist/assets/1x1 R3-C7WHg33m.stl
dist/assets/1x1.25 R1-BTIr3D3i.stl
dist/assets/1x1.25 R2-jyywTm8G.stl
dist/assets/1x1.5 R2-BYpHddNk.stl
dist/assets/1x1.5 R3-DO9Z1B1d.stl
dist/assets/1x1.5 R4-Dm8Txsvt.stl
dist/assets/1x1.75 R1-Bo90p1ow.stl
dist/assets/1x1.75 R3-BIYnu4hX.stl
dist/assets/1x1.75 R4-D09ORx_c.stl
dist/assets/1x2 R1-t59L7Y_R.stl
dist/assets/1x2 R4-B8nouRfq.stl
dist/assets/1x2.25 R1-BjnI8IJX.stl
dist/assets/1x2.25 R2-BCx2EO4n.stl
dist/assets/1x2.25 R3-CNCmQNf8.stl
dist/assets/1x2.25 R4-CDf46tqj.stl
dist/assets/1x2.5 R1-ClbsR-en.stl
dist/assets/1x2.5 R2-CQJdyVL4.stl
dist/assets/1x2.5 R3-bn9iJfxd.stl
dist/assets/1x2.5 R4-DDGQGMGy.stl
dist/assets/1x6.25 R1-CkT0OtEM.stl
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

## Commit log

2026-03-09 Expand README with project phases and tasks
    Added detailed project phases for custom keyboard development including PCB design, housing design, firmware, and prototyping.
2026-04-03 Fix layout and add prebuilded files
    [keyboard-plate.dxf, keyboard-plate.stl, keyboard.kicad_pcb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]
2026-04-17 Update files
    [keyboard-plate.dxf, keyboard-plate.stl, keyboard.kicad_pcb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]
2026-04-19 Update files with prerenderer
    [Cherry MX Keycap.SLDPRT, cherry mx.IGS, cherry mx.SLDPRT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]
2026-04-19 WIP : divide backside case
    [1x1 R1.stl, 1x1 R2.stl, 1x1 R3.stl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]
2026-04-19 Union the plate into case
    [case-bottom.stl, case-top.stl]
2026-04-20 Finishing 3d files
    [Cherry MX Stabilizers.stl, battery-cover.stl, case-bottom.stl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]
2026-04-20 Add publishing and
    [1x1 R1-C5EL7BkD.stl, 1x1 R2-BPDmK7m8.stl, 1x1 R3-C7WHg33m.stl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]
2026-04-20 fix: fix minor issues
    [1_case-top.stl, 1_case-top_SLA.stl, 2_case-bottom.stl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]
2026-04-21 Update files to tranform two files from 3
    [1_case-top.stl, 1_case-top_SLA.stl, 2_case-bottom.stl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]
2026-04-21 Update shpaes
    [1_case-top.stl, 1_case-top_SLA.stl, 2_case-bottom.stl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]
2026-05-03 Create v2 version of own keyboard
    [1_case-top.stl, 1x1 R1.stl, 1x1 R2.stl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]
2026-05-03 Adjust heights for pcb/plate and overall size for cases
    [49-pcba-housing-bottom.stl, 49-pcba-housing-top.stl, keyboard-plate-extended.dxf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]
2026-05-03 Adjust stl logic
    [keyboard-plate-extended.stl]
2026-05-03 Finalize V2 before create PCB
    [49-pcba-housing-bottom.stl, 49-pcba-housing-top.stl]
2026-05-09 Cutoff usb-c hole and add esp32-s3
    [49-pcba-housing-bottom.stl, keyboard.dsn, keyboard.kicad_pcb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]
2026-05-09 Update PCB with routing
    [keyboard.kicad_pcb, keyboard.kicad_sch]
2026-05-09 Clean up files with completed PCB rendering
    [keyboard.dsn, keyboard.kicad_pcb, keyboard.kicad_sch]
2026-05-09 Finalize v2 with pcb, case files
    [49-pcba-housing-bottom.stl, 49-pcba-housing-top.stl, bom.csv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]
2026-05-09 Clean up model preview with generated PCB from kicad
    [keyboard-B_Cu.gbl, keyboard-B_Mask.gbs, keyboard-B_Paste.gbp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]
2026-07-08 chore: main을 브랜치 안내로 재구성 — v1/v2/split 소개 + 브랜치별 Pages 통합 배포 워크플로
    [1_case-top.stl, 1x1 R1.stl, 1x1 R2.stl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]
2026-07-08 docs: README 문구 정리
2026-07-08 docs: README 사족 제거
